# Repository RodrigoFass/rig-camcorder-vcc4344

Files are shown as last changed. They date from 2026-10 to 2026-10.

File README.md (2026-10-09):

# Rig camcorder para a Sanyo VCC-4344

Este rig transforma uma câmera de CCTV analógica (Sanyo VCC-4344) numa filmadora de mão com cara de VHS. Ele é **100 % impresso em 3D**: não usa nenhum parafuso, porca ou peça de metal, e a câmera fica só encaixada, sem usar os parafusos dela.

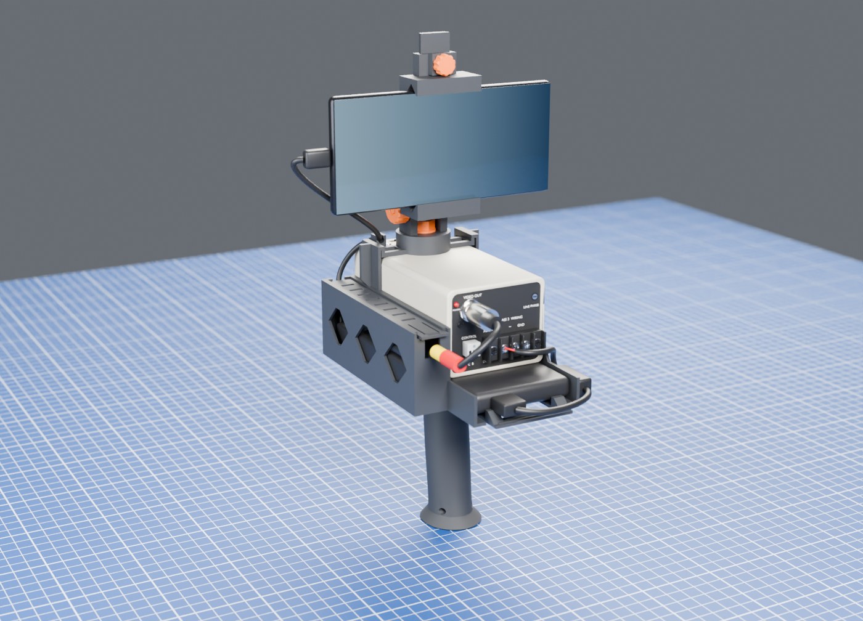
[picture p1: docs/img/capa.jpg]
Render do rig montado
<p align="center"><br><sub>Render do modelo. As travas extras aparecem nas imagens dos passos de montagem.</sub></p>

- **Câmera:** fica num berço que também guarda o power bank e a EasyCap.
- **Celular:** um Android serve de monitor e gravador. Ele fica numa articulação com giro, inclinação e rolagem.
  - **Opção fixa:** um clip de mola do MakerWorld, preso na base do giro, sem articulação. Veja [Suporte fixo do celular](docs/SUPORTE_CLIP.md).
- **Modelo paramétrico:** um único arquivo OpenSCAD (`scad/camcorder_rig_v6.scad`) gera todas as peças. As medidas da câmera, do power bank, da EasyCap, do celular e as folgas ficam no começo do arquivo.
- **Filamento:** ~180 g no rig completo (~80 g de PETG e ~100 g de PLA), mais ~16 g das peças de teste.

## Como cada parte prende

| Parte | Como prende |
|---|---|
| **Câmera** | Entra por trás no berço. O ferro (a chapa de suporte embaixo da câmera) corre sobre a sela, entre duas bochechas, até bater num batente. |
| **Ponte do topo** | Entra por trás, por baixo dos lábios das duas colunas. Os lábios descem para a frente, então a ponte funciona como cunha e aperta a câmera quando é empurrada. Uma moldura (trava da ponte) segura as colunas juntas. |
| **Power bank** | Molas no fundo do berço e uma trava traseira de encaixe. |
| **Cabo (empunhadura)** | Baioneta em rabo de andorinha: 2 garras sobem pelas janelas do berço e correm 13 mm para a frente. Uma chave trava. Veja [como o cabo prende](docs/img/como_o_cabo_prende.png). |
| **Giro, inclinação e rolagem** | Parafusos, porcas e botões impressos, com rosca de 8 mm e passo de 2 mm. A rosca é direita (aperta no sentido horário). |
| **Celular** | Garra com mordente que desliza e trava. A abertura (lado menor + espessura do celular) vai de ~68 a ~88 mm; o S21 dá 71,2 + 7,9 = 79,1 mm. Uma trava lateral com 2 cursores segura o celular nas pontas, para celulares de ~140 a ~172 mm de comprimento. Veja [como funciona](docs/img/como_funciona_trava_celular.png). |
| **EasyCap** | Caixa fechada do lado esquerdo do berço, com tampa deslizante e espaço para o adaptador OTG e as sobras de cabo. |

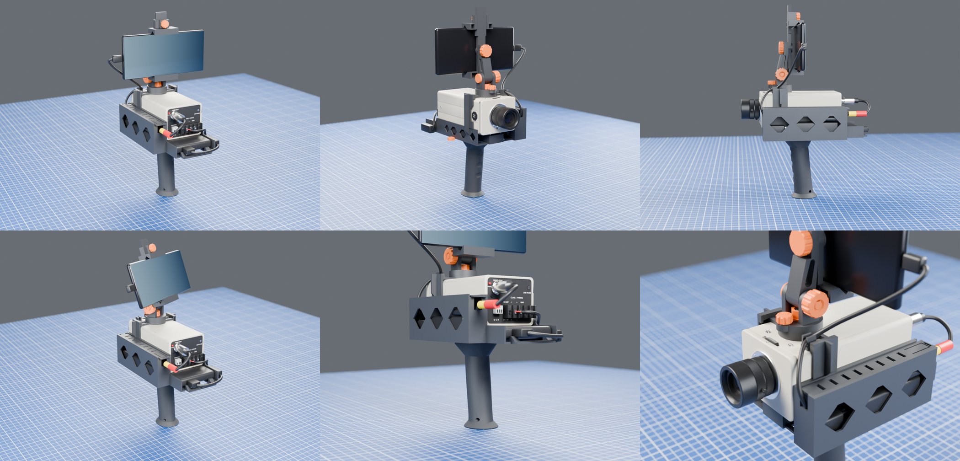
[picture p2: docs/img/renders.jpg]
Renders do rig


> **Lados:** "esquerdo" e "direito" são de quem segura o rig por trás, com a lente apontando para a frente. A caixa da EasyCap fica à esquerda e a chave do cabo entra pela direita.

## O que você precisa além das peças impressas

| Item | Observação |
|---|---|
| Câmera Sanyo VCC-4344 com lente CS | Medidas do modelo: corpo 67 × 126,5 × 54 mm. |
| Power bank | O modelo assume 124 × 67 × 13 mm. As molas absorvem ±1 mm na espessura. |
| Cabo USB 5 V → 12 V (step-up) | Alimenta a câmera pelo power bank. Prenda com 2 abraçadeiras ou barbante. |
| EasyCap (captura USB de vídeo AV) | O modelo assume 73 × 26 × 15,5 mm. **Nem toda EasyCap funciona no Android**: teste antes com um app de câmera USB. |
| Adaptador OTG (USB-A fêmea → USB-C) | Fica dentro da caixa. |
| Cabo BNC → RCA | Liga a saída de vídeo da câmera à EasyCap. |
| Celular Android | O modelo de referência é o Galaxy S21. No **iPhone** não funciona, porque o iOS não deixa apps usarem placas de captura USB. |
| EVA adesivo fino (opcional) | Dentro das mandíbulas da garra. |

## Peças

| Peça | Arquivo em `stl/` | Mesa (`mesas/`) | Qtd |
|---|---|---|---|
| Berço | `berco.stl` | 2 (PETG) | 1 |
| Tampa da caixa da EasyCap | `tampa.stl` | 2 (PETG) | 1 |
| Cabo | `cabo.stl` | 3 (PLA) | 1 |
| Ponte do topo (com o pino rosqueado do giro) | `topo.stl` | 3 (PLA)* | 1 |
| Garfo, braço, garra e mordente | `garfo.stl`, `braco.stl`, `garra.stl`, `mordente.stl` | 3 (PLA) | 1 de cada |
| Parafuso e porca-botão da inclinação, parafuso-botão da rolagem, parafusos de trava do giro e do mordente, porca e arruela em D do giro, chave do cabo | `parafusos.stl` | 4 (PLA) | 8 peças |
| Trava da ponte (moldura) | `trava_ponte.stl` | 5 (PETG) | 1 |
| Trava lateral do celular: calha, 2 cursores e 2 botões | `trava_celular.stl` | 6 (PLA) | 5 peças |
| Provas de encaixe | `testes_pla.stl`, `testes_petg.stl` | 1a / 1b | — |
| Porca-botão do suporte fixo (só na [opção com clip](docs/SUPORTE_CLIP.md)) | `porca_clip.stl` | 8 (PLA) | 1 |

\* A ponte fica apertada o tempo todo. Se ela ceder com o tempo, reimprima em PETG.

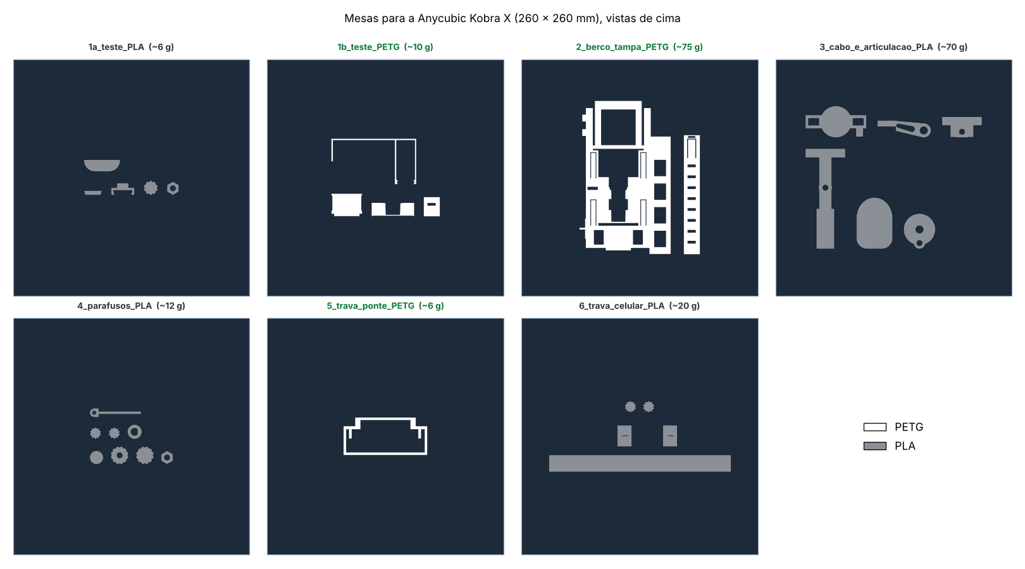
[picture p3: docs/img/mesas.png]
Mesas de impressão


As configurações do fatiador estão em [docs/COMO_IMPRIMIR.md](docs/COMO_IMPRIMIR.md). Nenhuma peça precisa de suporte. As maiores são o berço (101 × 169 × 78 mm), a calha da trava do celular (200 mm de comprimento) e o cabo (105 mm de altura, impresso em pé).

## Antes de imprimir: provas e ajustes

Imprima as mesas **1a** (PLA) e **1b** (PETG) e confira cada prova. Se algo ficar justo ou folgado, mude o parâmetro no começo do `.scad`:

| Prova | Deve ficar | Parâmetro |
|---|---|---|
| Parafuso + porca | Entra só com os dedos, sem ficar bambo | `TH_CL` (folga da rosca, 0,3 mm) |
| Garra do cabo + canal da baioneta | Corre e aperta no fim do curso | `DV_CL` |
| Espinha + mordente | Desliza sem folga | `SP_CL` |
| Sela | O ferro da sua câmera entra entre as bochechas sem forçar | `BRK_UW` (largura do ferro, 21,6 mm) |
| Fatia do berço | A câmera e o power bank cabem com folga pequena | `CL`, `PB`, `CAM_W` |
| Pedaço da tampa | Corre nos trilhos da fatia | `LID_X0`, `LID_X1`, `GR_Z1` (folgas da tampa) |

Os `.3mf` não se atualizam sozinhos. Depois de mudar um parâmetro, gere o STL de novo e importe no fatiador:

```bash
openscad -D 'PART="berco"' -o stl/berco.stl scad/camcorder_rig_v6.scad
```

Os nomes de `PART` são: `topo`, `berco`, `tampa`, `cabo`, `garfo`, `braco`, `garra`, `mordente`, `parafusos`, `trava_ponte`, `trava_celular`, `testes_pla` e `testes_petg`. Com `PART="montagem"`, o arquivo mostra tudo montado.

## Montagem

Não precisa de ferramenta. Cada passo indica para que lado ele é feito.

1. **Cabo:**
   - Vire o berço de cabeça para baixo.
   - Encaixe as 2 garras do topo do cabo nas 2 janelas do fundo do berço, com o cabo uns 13 mm para trás.
   - Empurre o cabo para a frente até parar firme.
   - Enfie a chave pelo rasgo de baixo do lado **direito** até a argola encostar.
   - Para tirar: puxe a chave pela argola e empurre o cabo para trás.
2. **Câmera:**
   - Apoie a câmera no berço, atrás das colunas, com o ferro na altura da sela.
   - Deslize para a frente até o ferro bater no batente. A bucha do ferro corre num canal da sela.
3. **Power bank:**
   - Empurre por trás, com as portas para trás, até a trava estalar.
   - Para tirar: aperte a ponta da trava (a cauda com ranhuras) para baixo e puxe.
4. **Ponte do topo e trava da ponte:**
   - Apoie a ponte em cima da câmera, atrás das colunas, com o gancho para a frente.
   - Empurre a ponte para a frente, por baixo dos lábios, até ficar bem firme.
   - Encaixe a trava da ponte por cima, em volta das duas colunas e da base do giro. Isso tem que ser feito **antes** de colocar o garfo.

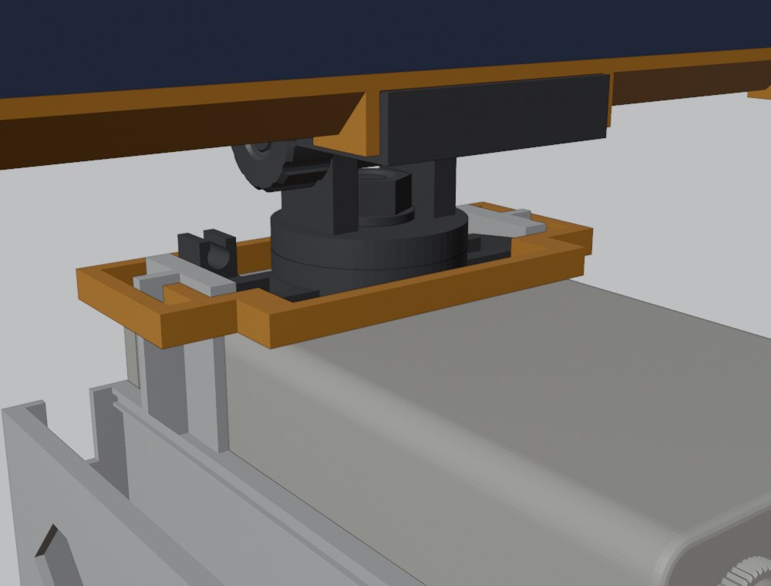
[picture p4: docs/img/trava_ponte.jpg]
Trava da ponte
   
5. **Giro:**
   - Coloque o garfo no pino, a arruela com furo em D e a porca sextavada.
   - Aperte até o garfo girar firme.
   - Rosqueie o parafuso da trava do giro na orelha da frente do garfo.
6. **Inclinação:**
   - Ponha o braço entre as orelhas do garfo.
   - Passe o parafuso pela orelha **direita**, com a face plana para cima, encaixando no furo em D.
   - Rosqueie a porca-botão do lado esquerdo.
7. **Rolagem:** encoste a garra atrás do braço e passe o parafuso-botão pela frente do braço, rosqueando na garra.
8. **Trava do celular e celular:**
   - Enfie um cursor em cada ponta da calha, com os botões para baixo e as paredes viradas para o meio.
   - Rosqueie um botão em cada cursor.
   - Encaixe a calha no V da garra de baixo, com os dedos abraçando as pontas da garra.
   - Ponha o celular com o USB-C para a esquerda.
   - Encoste os cursores nas pontas do celular e aperte os botões.
   - Enfie o mordente pelo topo da espinha, desça até encostar no celular e aperte o botão do mordente com firmeza.

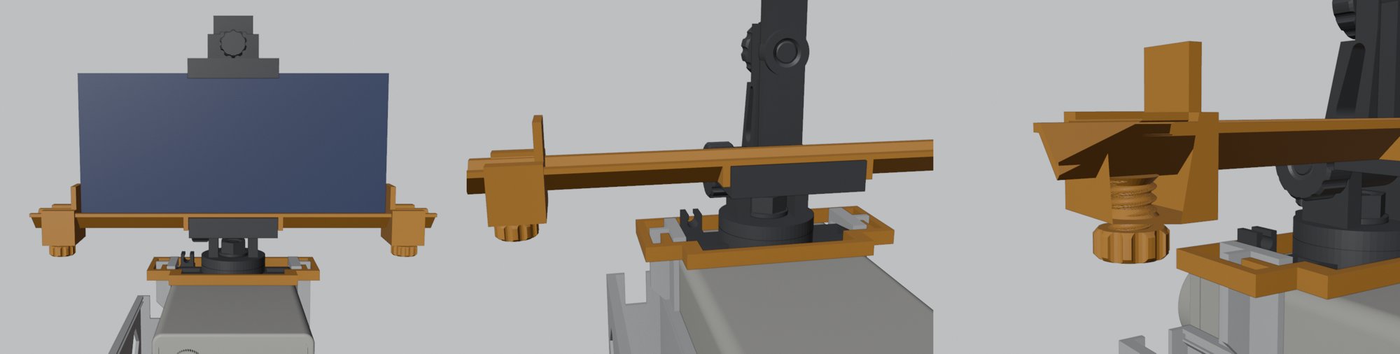
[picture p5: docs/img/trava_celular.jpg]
Trava lateral do celular
   
9. **EasyCap:**
   - Puxe a tampa da caixa pela ponta de trás, no rasgo para a unha.
   - Deite a EasyCap no fundo da caixa, com o USB para a frente, e encaixe o adaptador OTG.
   - Passe o cabo OTG pelo rasgo da frente e o RCA pelo rasgo de trás. As sobras de cabo ficam por cima.
   - Deslize a tampa por trás até clicar.

## Ligações

1. **Alimentação:**
   - Ligue o power bank ao cabo USB 5 V → 12 V e os fios aos bornes **DC 12V + e −** da câmera.
   - Prenda o step-up com abraçadeiras nas presilhas do lado direito do berço.
   - Confira a polaridade com multímetro antes de ligar. Não ligue nada nos bornes da entrada AC 24 V.
2. **Vídeo:** BNC "VIDEO OUT" → cabo BNC/RCA → RCA amarelo da EasyCap.
3. **Celular:**
   - Ligue o adaptador OTG ao celular passando pelo rasgo da frente e pelo gancho da ponte. Deixe uma folga perto da articulação.
   - No celular, use um app de câmera USB.

## Movimentos do celular

| Movimento | Faixa |
|---|---|
| Giro | 360° |
| Inclinação | −35° a +95° |
| Rolagem | ±30° |
| Inclinar para trás e rolar ao mesmo tempo | Com ±15° de rolagem, vai até −25°. Com ±30°, não incline para trás. |

## Verificações (`tools/`)

Os scripts conferem colisões entre todas as peças e a câmera (usando o modelo aproximado em `ref/`), varrem os movimentos do celular, calculam o centro de massa e estimam o filamento. Rode da raiz do repositório. Precisa de OpenSCAD 2021+ e Python 3 com os pacotes do `requirements.txt`.

```bash
pip install -r requirements.txt
bash tools/build6.sh asm_ topo berco tampa cabo chave porca trava_ponte garfo trava bincl braco garra brol mordente bmord trava_celular
python3 tools/check6.py          # colisões e movimentos
python3 tools/cog6.py            # centro de massa e estabilidade em pé
python3 tools/filamento.py stl/*.stl
```

**Resultado da v6:**
- **Colisões:** nenhuma entre as peças, nas faixas de movimento da tabela acima.
- **Equilíbrio:** o centro de massa fica a ~4 mm da mão.
- **Em pé:** o rig só tomba com mais de ~6° de inclinação.

## Glossário

- **Ferro:** a chapa de metal embaixo da câmera, onde normalmente vai a rosca de tripé.
- **Sela e bochechas:** o apoio do ferro no berço e as duas paredes que o guiam dos lados.
- **Lábios:** as abas no alto das colunas que seguram a ponte por cima.
- **Mordente:** a mandíbula de cima da garra do celular, que desliza na espinha.
- **OTG:** adaptador que deixa o celular usar um aparelho USB.
- **Step-up:** conversor que sobe os 5 V do power bank para os 12 V da câmera.
- **BNC:** o conector de vídeo da câmera.

## Histórico

- **v1–v4:** protótipos. Usavam os parafusos da câmera, uma luva e um pino impresso rosqueado no ferro, que quebrava.
- **v5:** berço sem os parafusos da câmera, caixa da EasyCap, garra ajustável e ~150 g de filamento. Ainda usava ferragens de metal.
- **v6 (atual):** 100 % impresso, com ponte em cunha, cabo em baioneta e roscas impressas. Depois do primeiro teste montado vieram a trava da ponte, a trava lateral ajustável do celular e parafusos de trava mais longos.

## Licença

© 2026 Rodrigo ([RodrigoFass](https://github.com/RodrigoFass)).

- **Peças, modelos e documentação** (`scad/`, `stl/`, `mesas/`, `docs/`, `ref/`): [CC BY-SA 4.0](LICENSE-HARDWARE.txt). Você pode usar, modificar e vender, desde que dê o crédito e compartilhe as modificações com a mesma licença.
- **Scripts** (`tools/`): [MIT](tools/LICENSE).

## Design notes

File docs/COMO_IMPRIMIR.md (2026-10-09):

# Como imprimir

As mesas da pasta `mesas/` foram montadas para a **Anycubic Kobra X** (mesa de 260 × 260 mm) e o **Anycubic Slicer Next**, mas abrem em qualquer fatiador que leia `.3mf`. As peças já vêm na posição certa. O material está no nome do arquivo, e no fatiador cada peça aparece como "PETG - …" ou "PLA - …". Em outra impressora, use os STLs da pasta `stl/`: eles já estão na posição de impressão.

| Ordem | Arquivo | Material | Filamento* |
|---|---|---|---|
| 1 | `1a_teste_PLA.3mf` | PLA | ~6 g |
| 1 | `1b_teste_PETG.3mf` | PETG | ~10 g |
| 2 | `2_berco_tampa_PETG.3mf` | PETG | ~75 g |
| 3 | `3_cabo_e_articulacao_PLA.3mf` | PLA | ~70 g |
| 4 | `4_parafusos_PLA.3mf` | PLA | ~12 g |
| 5 | `5_trava_ponte_PETG.3mf` | PETG (ou PLA) | ~6 g |
| 6 | `6_trava_celular_PLA.3mf` | PLA | ~20 g |
| 7 | clip do celular (opção fixa, [gere você mesmo](SUPORTE_CLIP.md)) | PETG | ~30 g |
| 8 | `8_porca_clip_PLA.3mf` (opção fixa) | PLA | ~3 g |

Na opção fixa com o clip, não precisa de garfo, braço, garra e mordente (mesa 3), da mesa 6 nem dos parafusos da articulação (mesa 4). A chave do cabo, que também sai na mesa 4, continua necessária.

\* Estimativa. O fatiador mostra o peso exato.

**Por que PETG no berço:** ele tem molas e travas que flexionam e fica encostado na câmera, que esquenta. O PLA amolece por volta de 55 °C e pode ceder.

## Configuração

### Mesas 1a, 1b, 2, 3 e 5
- **Processo:** 0.20mm Standard (camada de 0,2 mm).
- **Resistência:**
  - 3 paredes;
  - 4 camadas sólidas em cima e embaixo;
  - preenchimento de 15 % em **Giroide**. Evite Grade, que faz o bico raspar nas linhas já impressas.
- **Suporte:** desligado.
- **Borda (brim):** sem borda. A exceção é o cabo, na mesa 3: ligue brim de 5 mm só nele, porque ele imprime em pé. No Anycubic Slicer, clique com o botão direito no cabo e use a aba **Objetos**.
- **Velocidade:** com PETG, deixe a parede externa do berço em ~100 mm/s. As colunas são altas e finas.

A mesa 1a usa a mesma configuração da mesa 3 de propósito: assim a prova da rosca reproduz as roscas do garfo, da garra, do mordente e da ponte, que saem na mesa 3.

### Mesas 4 e 6 (parafusos, porcas, cursores)
- Camada de **0,12 mm**
- **5 paredes**
- **40 %** de preenchimento
- Parede externa a ~60 mm/s

### PETG em mesa de PEI liso
Passe cola bastão antes de imprimir. Sem ela, o PETG gruda demais e pode arrancar a película da mesa.

## Provas de encaixe

Imprima as mesas 1a e 1b antes das peças grandes. A tabela com o que conferir e qual parâmetro ajustar está no [README](../README.md#antes-de-imprimir-provas-e-ajustes).

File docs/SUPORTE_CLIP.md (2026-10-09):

# Suporte fixo do celular (clip do MakerWorld)

Esta opção troca a articulação (giro, inclinação e rolagem) por um suporte fixo. O celular fica num clip de mola preso na base do giro da ponte, com a tela para o operador e inclinado 15° para trás, com a tela apontando um pouco para cima.

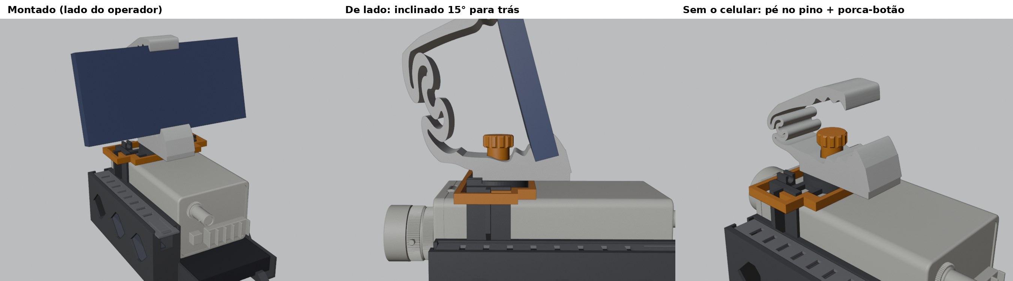
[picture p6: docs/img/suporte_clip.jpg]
Suporte fixo com o clip


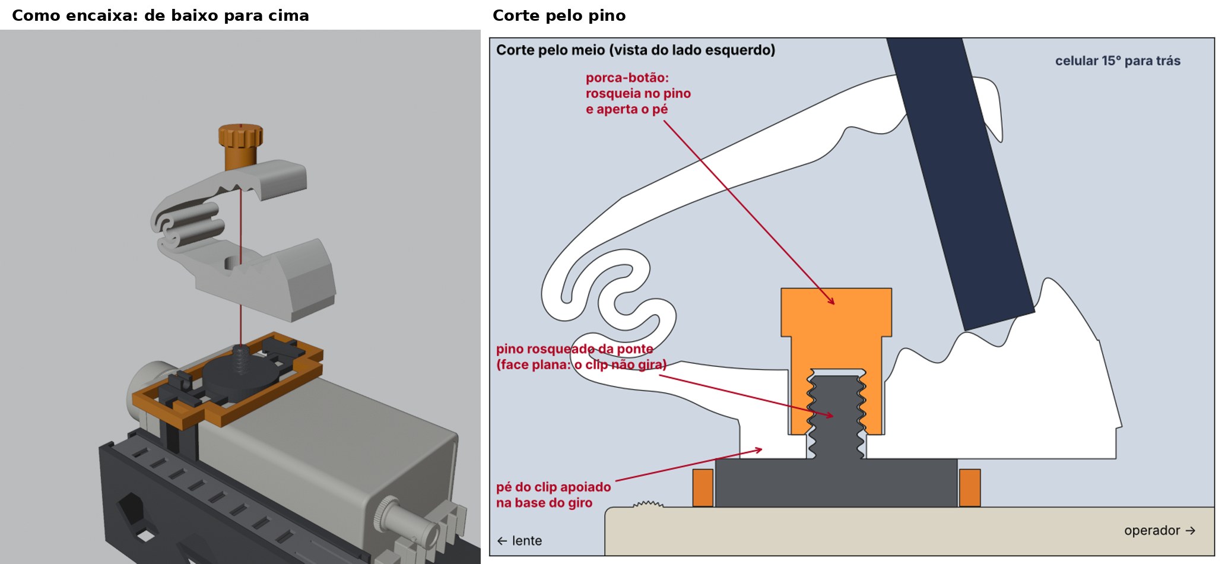
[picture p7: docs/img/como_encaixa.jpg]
Como o clip encaixa na ponte


O clip é o [Ultimate Desk & Cockpit Phone Holder Clip v3](https://makerworld.com/models/1158094), de **RealNationPrint**, impresso a 110 %, como no perfil do autor.
- **A garra de cima, com a mola em espiral,** segura o celular deitado pela altura. O fundo do celular fica nos dentes, atrás do lábio da frente, e a ponta da garra prende o topo.
- **A garra de baixo,** que prendia o clip no painel do carro, foi tirada.
- **No lugar dela entra um pé,** com furo em D que encaixa no pino do giro. A face plana do pino impede o clip de girar.
- **Uma porca-botão** rosqueia no pino por cima e aperta o pé contra a base.
- **Inclinação:** o corpo do clip é inclinado 15° em cima do pé, que continua reto na base. Para mudar, altere `CL_INC` no `.scad`.

## O arquivo do clip não vem neste projeto

A licença do autor (Standard Digital File License) não permite redistribuir o modelo nem versões modificadas dele. Por isso o perfil do clip não está no repositório. Para gerar o clip adaptado:

1. Baixe o `.3mf` do clip na página do MakerWorld.
2. Na raiz do repositório, rode:
   ```
   python3 tools/clip_perfil.py ClipV3.3mf
   ```
   Isso grava `scad/clip_v3_perfil.scad`, que fica fora do git.
3. Gere as peças:
   ```
   openscad -D 'PART="clip"' -o clip.stl scad/camcorder_rig_v6.scad
   openscad -D 'PART="porca_clip"' -o porca_clip.stl scad/camcorder_rig_v6.scad
   ```

O arquivo gerado é só para uso pessoal.

## Impressão

| Peça | Material | Configuração | Filamento* |
|---|---|---|---|
| Clip (`PART="clip"`) | **PETG** | Deitado, com o perfil na mesa. Camada de 0,2 mm, 3 paredes, 25 % de preenchimento, sem suporte. | ~30 g |
| Porca-botão (`PART="porca_clip"`) | PLA | Botão na mesa. Mesma configuração das porcas (mesa 4): camada de 0,12 mm, 5 paredes, 40 %. | ~3 g |

\* Estimativa. O fatiador mostra o peso exato.

- **Por que PETG no clip:** a mola em espiral flexiona muito para o celular entrar. Em PLA ela pode trincar.
- **Furos sem suporte:** o furo em D sai com o teto reto e o rebaixo da porca sai em gota.

## Montagem

1. **Peças da articulação:** tire o garfo e tudo o que fica nele: braço, garra, mordente, os parafusos e a porca sextavada do giro com a arruela.
   - A ponte, a trava da ponte (moldura) e o resto do rig ficam como estão.
2. **Clip:**
   - Encaixe o pé do clip no pino do giro, com a mola em espiral para a frente (lado da lente) e os dentes para trás.
   - O furo em D só entra numa posição.
3. **Porca-botão:**
   - Coloque a porca-botão no pino por cima do corpo do clip.
   - Aperte com os dedos, no sentido horário, até o pé ficar firme.
4. **Celular:**
   - Levante a garra de cima.
   - Apoie o celular nos dentes, com a tela para trás e encostado no lábio.
   - Solte a garra sobre o topo do celular.
   - Deixe o USB-C para a esquerda, do lado da EasyCap.

**Opcional:** EVA fino adesivo nos dentes, para o celular não escorregar para os lados.

## Conferido no computador

- **Interferências:** o clip não bate na câmera nem na trava da ponte. Ficam 7 mm até o topo da câmera e 1,5 mm até a moldura.
- **Folgas:**
  - furo em D no pino: 0,2 mm;
  - porca-botão no rebaixo: 0,4 mm;
  - botão até o corpo do clip: 2,3 mm.
- **Celular:**
  - Fica inclinado 15° para trás, de Z 52 a 126 mm, uns 6 mm mais baixo que na articulação.
  - Sobram 8 mm entre o celular e a porca-botão.
- **Equilíbrio:** o centro de massa fica ~1,5 mm atrás da mão. Antes ficava ~4 mm.
- **Em pé na mesa:** o rig só tomba se inclinar mais de ~6°.

Para refazer as contas: `tools/check_clip.py` e `tools/cog_clip.py`.

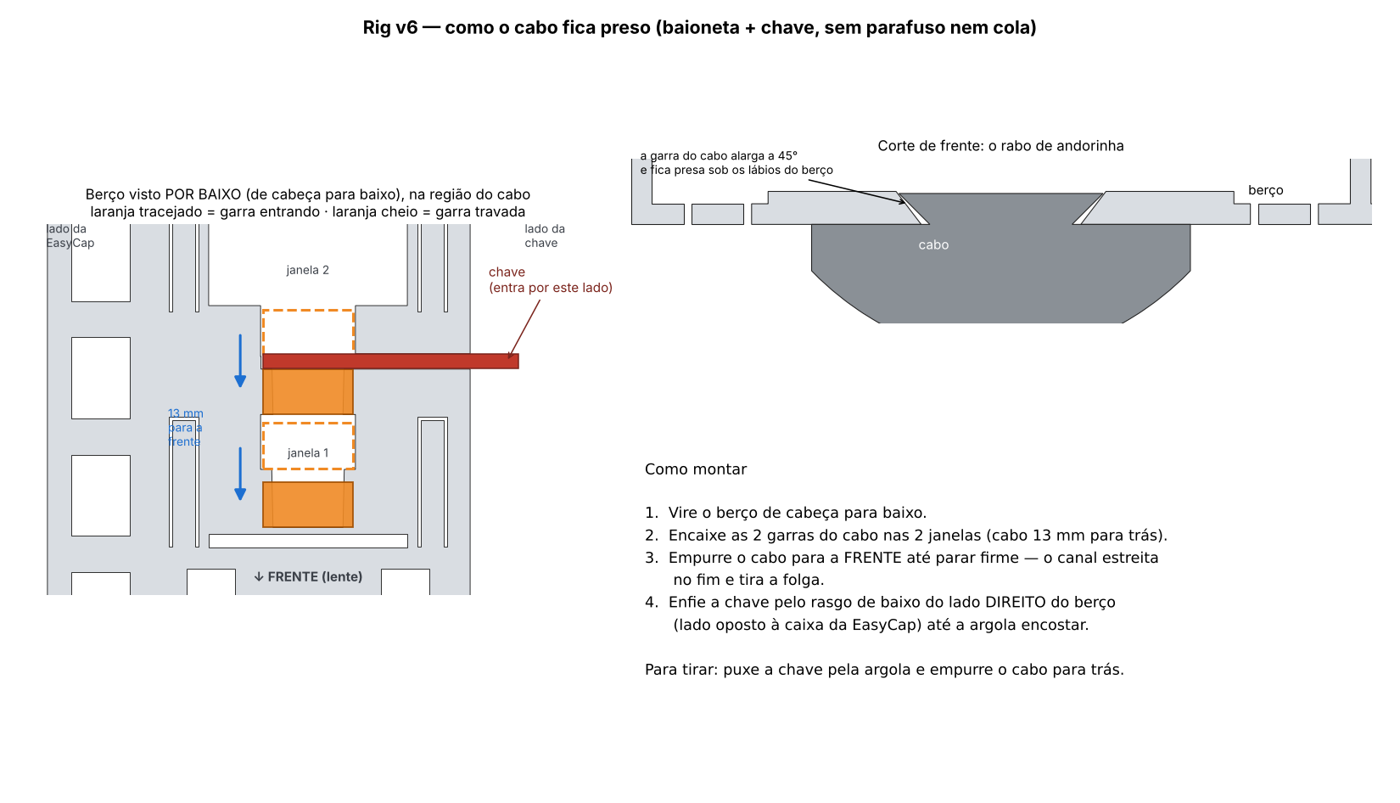
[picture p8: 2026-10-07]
docs/img/como_o_cabo_prende.png

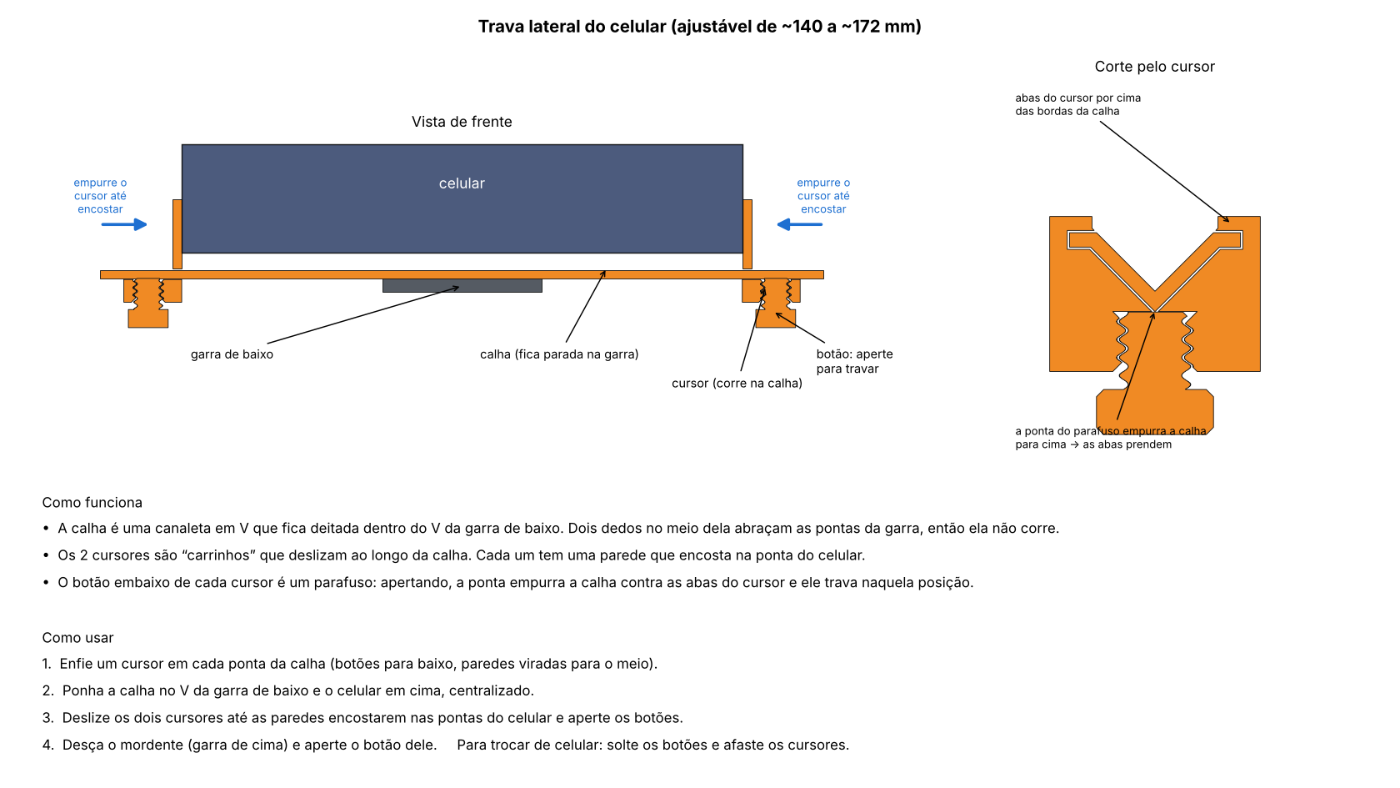
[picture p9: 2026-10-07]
docs/img/como_funciona_trava_celular.png

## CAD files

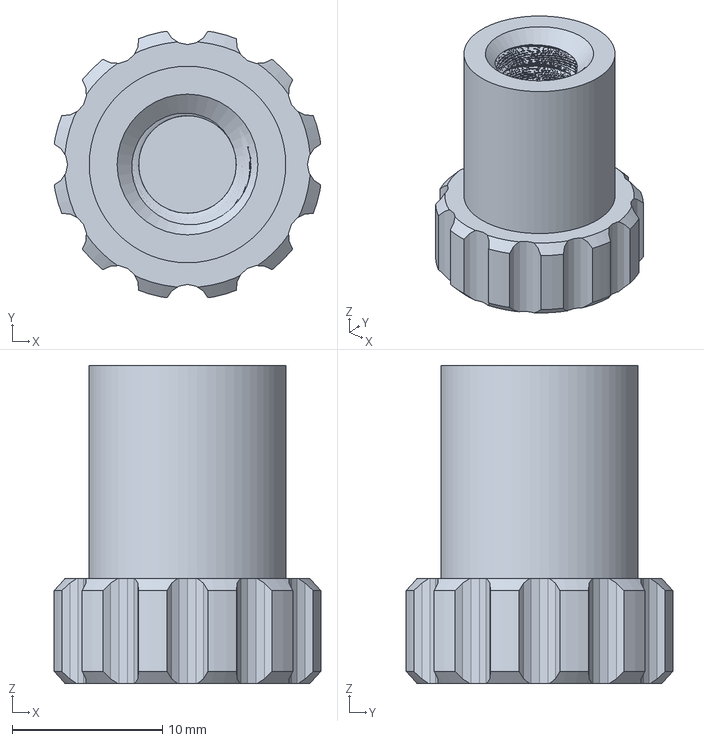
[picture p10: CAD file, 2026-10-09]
mesas/8_porca_clip_PLA.3mf
17.8 x 17.8 x 21.2 mm

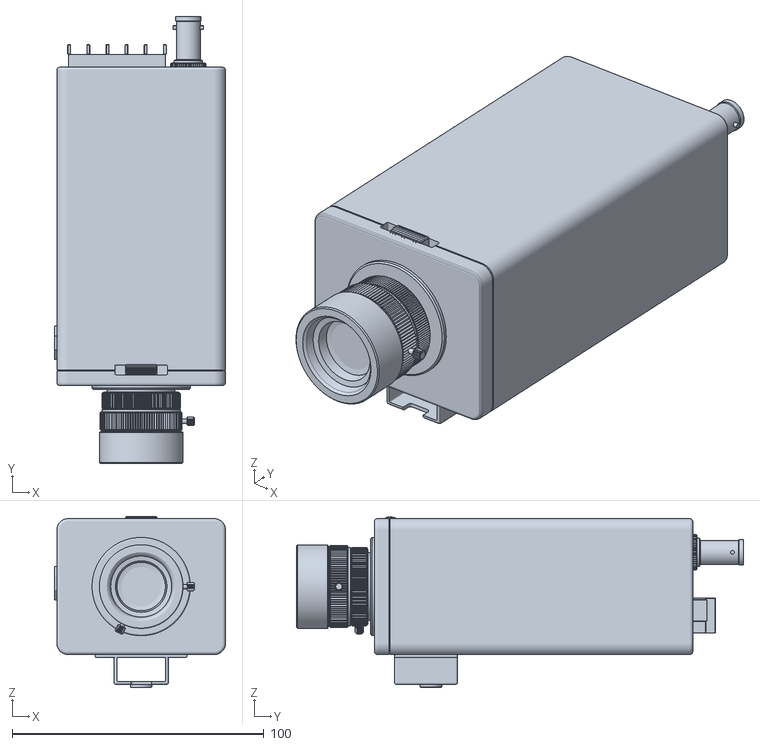
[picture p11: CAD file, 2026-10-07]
ref/sanyo_vcc4344_mm.stl
67.9 x 177.5 x 68.1

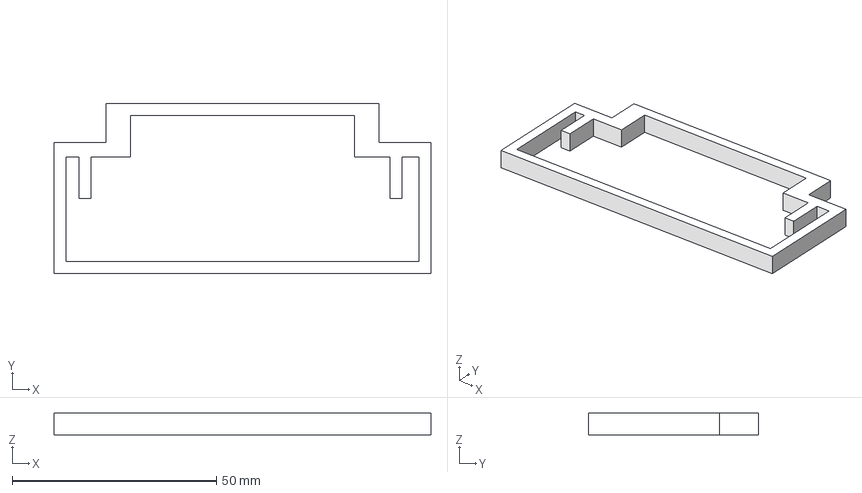
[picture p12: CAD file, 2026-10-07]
mesas/5_trava_ponte_PETG.3mf
92.4 x 41.7 x 5.35 mm

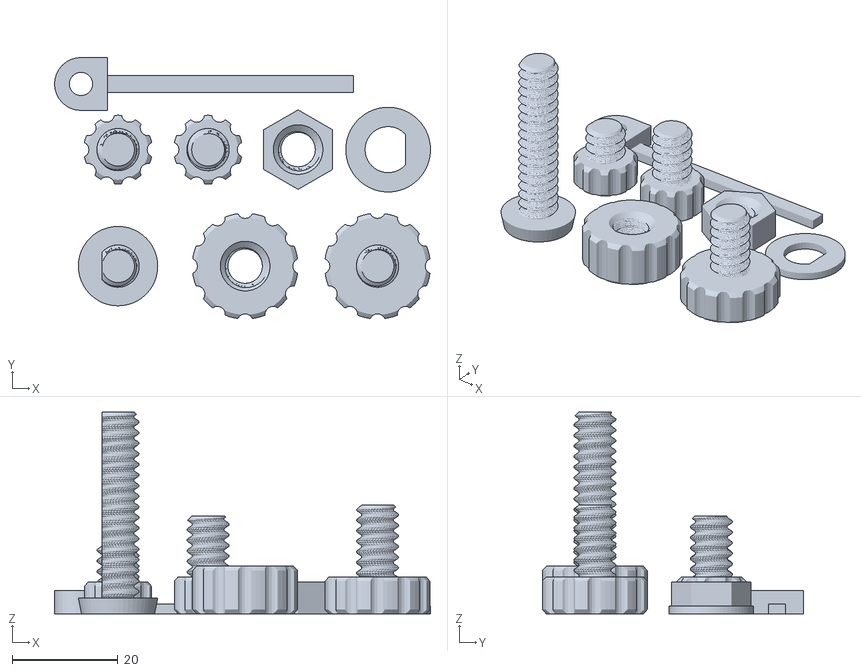
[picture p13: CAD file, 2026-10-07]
stl/parafusos.stl
71.0 x 49.3 x 38.1

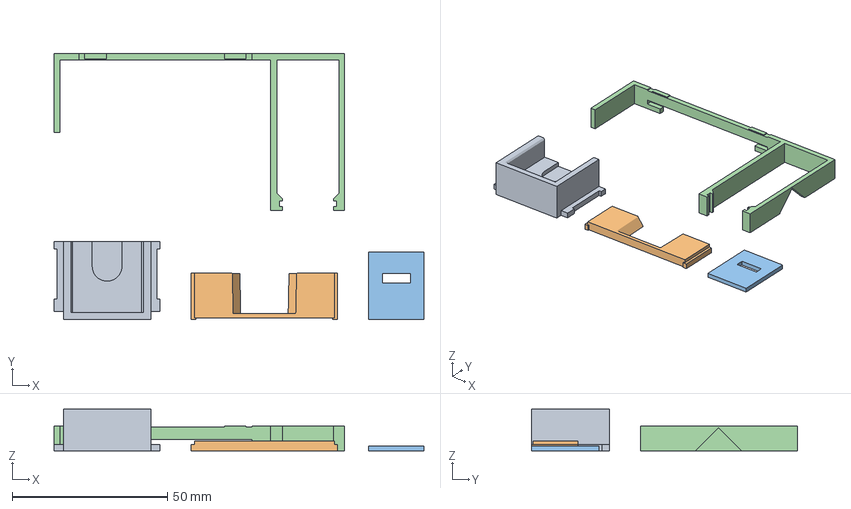
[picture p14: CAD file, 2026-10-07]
mesas/1b_teste_PETG.3mf
119.2 x 85.6 x 13.4 mm
PETG - teste_sela
PETG - teste_baioneta_berco
PETG - teste_tampa
PETG - teste_fatia_berco_e_caixa

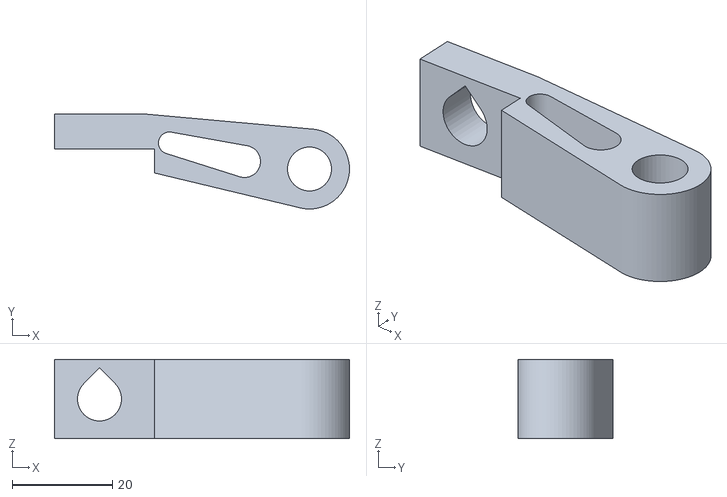
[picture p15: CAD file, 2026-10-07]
stl/braco.stl
59.0 x 19.0 x 15.8

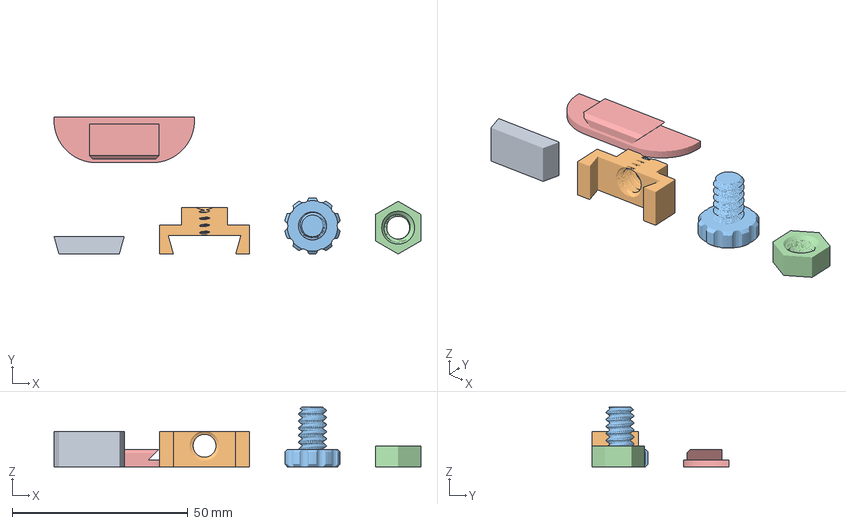
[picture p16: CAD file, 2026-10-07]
mesas/1a_teste_PLA.3mf
104.5 x 39.0 x 17.0 mm
PLA - teste_espinha_garra
PLA - teste_mordente
PLA - teste_rosca_parafuso
PLA - teste_rosca_porca
PLA - teste_baioneta_cabo

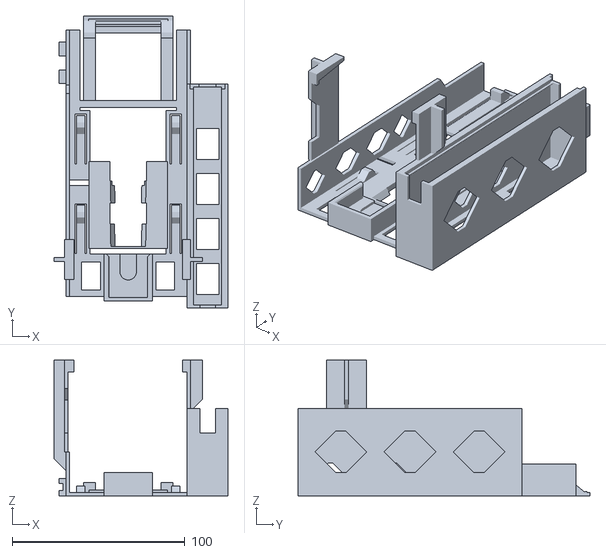
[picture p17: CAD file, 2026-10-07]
stl/berco.stl
100.6 x 168.9 x 78.4

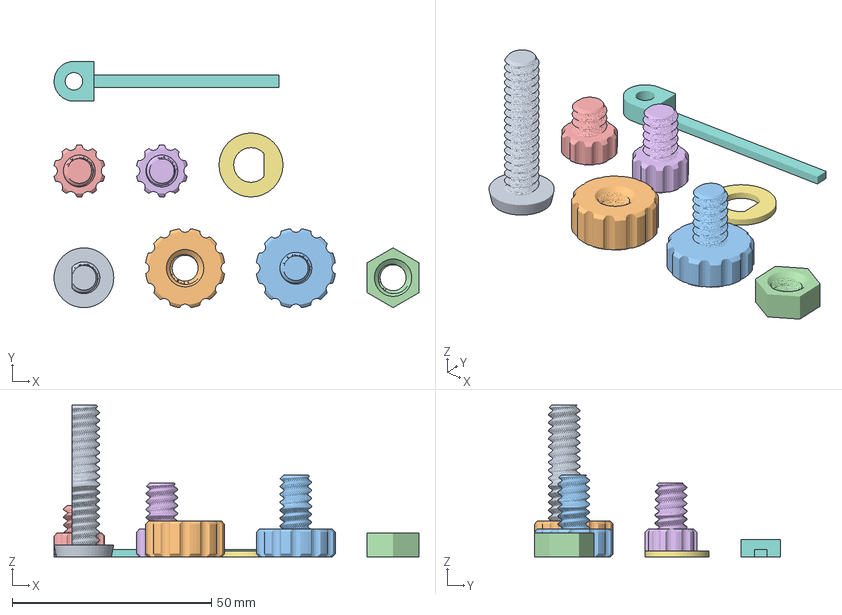
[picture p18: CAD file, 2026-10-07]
mesas/4_parafusos_PLA.3mf
91.6 x 61.8 x 38.1 mm
PLA - parafuso_inclinacao
PLA - porca_botao_inclinacao
PLA - parafuso_rolagem
PLA - porca_giro
PLA - parafuso_trava_giro
PLA - parafuso_mordente
PLA - arruela_giro
PLA - chave_do_cabo

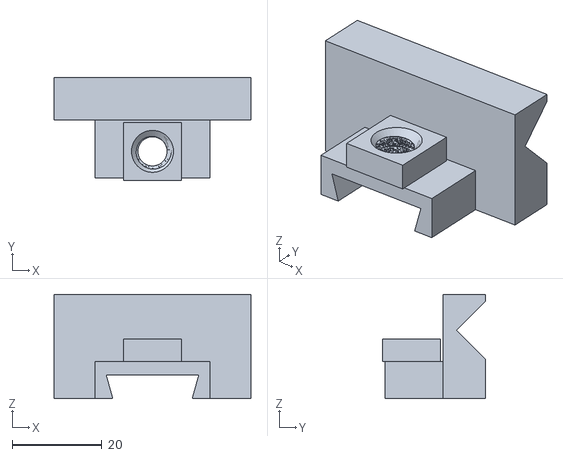
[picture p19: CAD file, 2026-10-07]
stl/mordente.stl
44.0 x 23.0 x 23.2

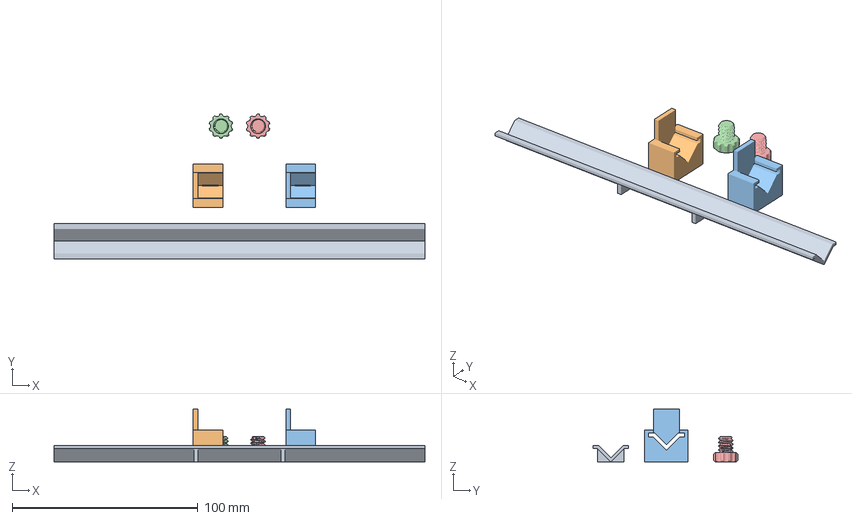
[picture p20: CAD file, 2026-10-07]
mesas/6_trava_celular_PLA.3mf
200.0 x 78.0 x 28.5 mm
PLA - calha
PLA - cursor_1
PLA - cursor_2
PLA - botao_cursor_1
PLA - botao_cursor_2

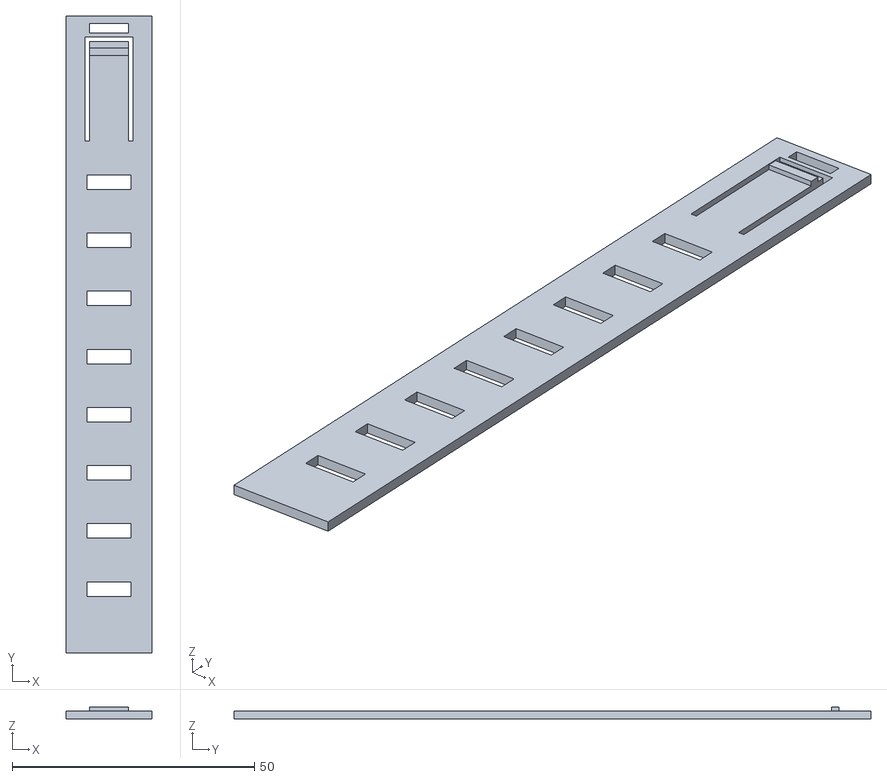
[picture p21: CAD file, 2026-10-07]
stl/tampa.stl
17.8 x 131.5 x 2.40

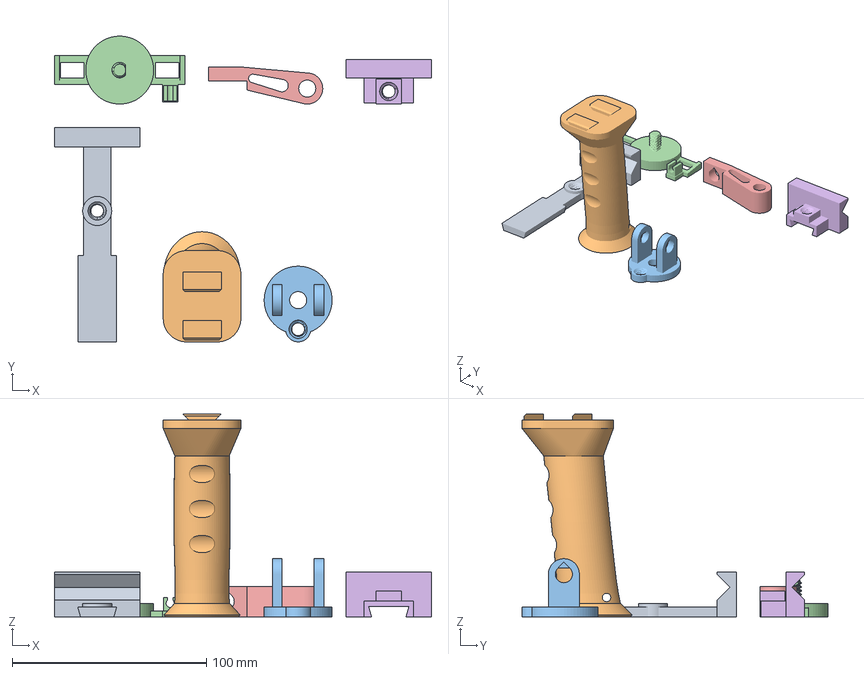
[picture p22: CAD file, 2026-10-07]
mesas/3_cabo_e_articulacao_PLA.3mf
194.2 x 157.5 x 104.5 mm
PLA - garra
PLA - cabo
PLA - garfo
PLA - ponte_topo
PLA - braco
PLA - mordente

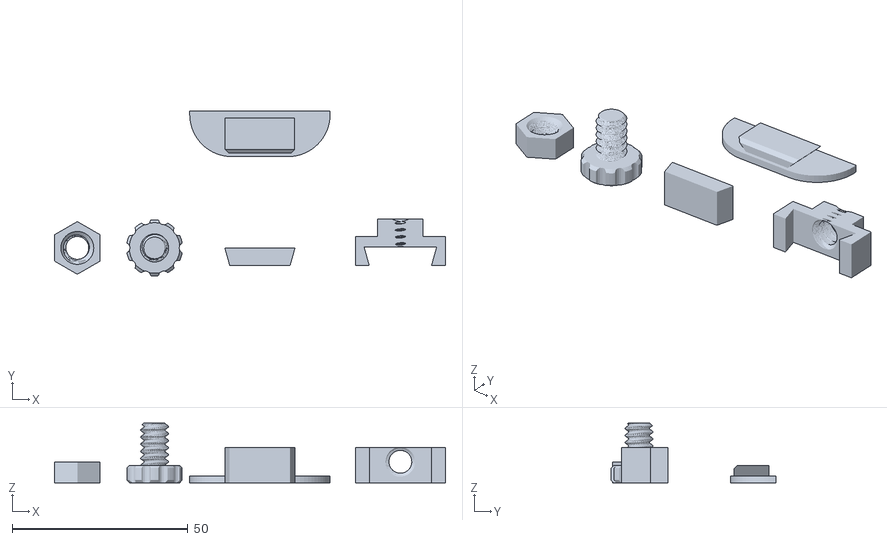
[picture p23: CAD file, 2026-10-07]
stl/testes_pla.stl
111.3 x 47.0 x 17.0

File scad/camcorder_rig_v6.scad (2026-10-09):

// SPDX-License-Identifier: CC-BY-SA-4.0   © 2026 Rodrigo (github.com/RodrigoFass)
// =====================================================================
//  Rig camcorder v6 — Sanyo VCC-4344  (100 % impresso: nenhum parafuso, porca ou peça de metal)
//  A câmera (metal) é a estrutura e fica só encaixada; nenhum parafuso da câmera é usado.
//  Tudo o que rosqueia é impresso: rosca de 8 mm, passo 2 (perfil liso de círculo excêntrico torcido).
//    • berço   : abraça a base da câmera. A câmera entra por trás: o ferro corre sobre a sela, entre
//                duas bochechas, até o batente da frente. Duas colunas com lábios em cunha seguram a
//                ponte do topo. Power bank preso por molas e trava traseira; EasyCap numa caixa fechada
//                no lado +X, com tampa deslizante.
//    • topo    : ponte que entra por trás sob os lábios das colunas e aperta a câmera ao ser empurrada
//                para a frente (cunha). O pino rosqueado do giro sai impresso junto.
//    • cabo    : empunhadura presa por baioneta em rabo de andorinha (2 garras entram por janelas e
//                correm 13 mm para a frente), travada por uma chave que entra pelo lado −X.
//    • garfo, braço, garra, mordente: giro, inclinação e rolagem do celular, com parafusos, porcas e
//                botões impressos. A garra abre de 70 a 90 mm (altura + espessura do celular).
//  Coordenadas (mm): X = largura (+X = esquerda do operador), Y = comprimento (lente em −Y),
//  Z = altura; origem no centro do corpo da câmera.
//    • extras : trava da ponte (moldura em volta das colunas) e trava lateral do celular ajustável
//    • opção fixa: clip de mola do MakerWorld na base do giro, no lugar da articulação (veja o fim do arquivo)
//  Uso: openscad -D 'PART="berco"' -o berco.stl camcorder_rig_v6.scad
//       PART = montagem (com o clip) | montagem_articulada | topo | berco | tampa | cabo | garfo | braco | garra |
//              mordente | parafusos | trava_ponte | trava_celular | clip | porca_clip | testes_petg | testes_pla
// =====================================================================

PART = "montagem";
$fn = 64;

// ---------------------------------------------------------- câmera (manual + fotos)
CAM_W = 67;  CAM_L = 126.5;  CAM_H = 54;  CAM_R = 4.5;
YF = -CAM_L/2;  YB = CAM_L/2;  ZT = CAM_H/2;  ZB = -CAM_H/2;
BRK_Y0 = YF + 8;  BRK_Y1 = YF + 33;  BRK_UW = 21.6;  BRK_H = 12;
BRK_ZB = ZB - BRK_H + 0.02;                  // fundo da chapa do ferro (−38,98)
BUCHA_Y = YF + 22.5;  BUCHA_R = 4.3;  BUCHA_H = 1.2;

// ---------------------------------------------------------- componentes (confira com paquímetro)
PB = [124, 67, 13];         // power bank: comprimento (Y), largura (X), espessura (Z)
EC_A = 73;  EC_B = 26;  EC_C = 15.5;  EC = [EC_A, EC_B, EC_C];        // EasyCap sem o plugue (scan: ~72 x 25,5 x 15): comprimento (Y), altura (Z), espessura (X)
PH = [151.7, 71.2, 7.9];    // celular na montagem (Galaxy S21): comprimento, altura, espessura

// ---------------------------------------------------------- roscas impressas
TH_D = 8;  TH_P = 2;        // diâmetro externo e passo
TH_E = 0.5;                 // excentricidade (a rosca tem 2·TH_E = 1 mm de profundidade)
TH_CL = 0.3;                // folga radial da fêmea (ajuste com a peça de teste)

// ---------------------------------------------------------- berço
CL = 0.4;  W = 2.0;                          // folga lateral e parede
XI = max(PB[1], CAM_W)/2 + CL;               // face interna das paredes (33,9)
XO = XI + W;                                 // face externa (35,9)
Z_PB0 = ZB - PB[2];                          // fundo do power bank (−40); o topo encosta na câmera
SPR_GAP = 2.4;                               // vão das molas embaixo do power bank
LIP_Z1 = Z_PB0 - SPR_GAP;                    // topo das abas (−42,4)
LIP_Z0 = LIP_Z1 - 2.0;                       // fundo do berço (−44,4)
XL = XI - 6;                                 // borda interna das abas (27,9)
WALL_Z1 = ZB + 8;                            // paredes sobem 8 mm nas laterais da câmera
WALL_Z1B = ZB + 1;                           // atrás da câmera só seguram o power bank
PB_Y0 = BRK_Y1 + 0.4;  PB_Y1 = PB_Y0 + PB[0];
CH_Y0 = BRK_Y0;  CH_Y1 = PB_Y1 + 5;
// sela sob o ferro: bochechas dos lados, batente na frente e canal da bucha (a câmera entra por trás)
SAD_Z1 = BRK_ZB - 0.02;  SAD_Y1 = PB_Y0 - 0.6;
SC_X0 = BRK_UW/2 + 0.3;  SC_X1 = SC_X0 + 3;  SC_Z1 = ZB - 4;      // bochechas (faces internas a 0,3 mm do ferro)
FEN_Y1 = BRK_Y0 - 0.35;  FEN_Y0 = FEN_Y1 - 2.25;                 // batente na frente do ferro
// molas: 4 linguetas que empurram o power bank contra a câmera (absorvem ±1 mm de espessura)
SPR_X = 27.5;  SPR_W = 5;  SPR_L = 28;  SPR_UP = 1.3;
SPR_YC = [PB_Y0 + 22, PB_Y0 + 74];           // crista das molas (sempre embaixo da câmera)
function spr_y0(yc) = yc - 22.5;
// trava traseira: lingueta em U no fundo; aperte a ponta para baixo para soltar
LAT_Y0 = PB_Y1 - 36;  LAT_X0 = 19;  LAT_X1 = 26;  LAT_T = 1.8;
HOOK_Y0 = PB_Y1 + 0.3;  HOOK_L = 3;  HOOK_Z = Z_PB0 + 3.2;  TAIL_Y1 = PB_Y1 + 13;
// caixa da EasyCap (+X): EasyCap deitada no fundo, adaptador OTG na frente, sobras de cabo por cima; tampa deslizante
EB_T = 1.8;                                  // paredes da caixa
EB_X0 = XO;  EB_X1 = XO + 20;                // faces internas (a de dentro é a parede do berço, prolongada)
EB_Y0 = -60;  EB_Y1 = 66;                    // faces internas da frente e de trás
EB_Z0 = LIP_Z0 + 2;  EB_Z1 = 2;              // fundo e topo do espaço interno
RL_W = 1.8;  GR_D = 1.0;  LID_T = 1.6;       // trilhos da tampa, fundo da canaleta, espessura da tampa
GR_Z0 = EB_Z1 + 1.0;  GR_Z1 = GR_Z0 + LID_T + 0.3;   // canaleta da tampa
RL_Z1 = GR_Z1 + 1.2;                         // topo dos trilhos e da frente
LID_X0 = EB_X0 + RL_W - GR_D + 0.3;  LID_X1 = EB_X1 - RL_W + GR_D - 0.3;
LID_Z0 = GR_Z0 + 0.15;  LID_Y1 = EB_Y1 + EB_T + 4;
// EasyCap na montagem: deitada no fundo, encostada na parede de fora, USB para a frente
EC_X0 = EB_X1 - EC[2] - 0.5;  EC_Y0 = -18;  EC_Z0 = EB_Z0;
TST_Y = 50.5;                                // fatia de teste do berço (inteira: travessa + caixa)
// janelas das paredes (ventilação e menos material)
WIN_Z0 = LIP_Z1 + 3.5;  WIN_Z1 = ZB + 1.5;
WIN_PX = [[-51, -35], [-15, 2], [12, 29.6]];
WIN_NX = [[-51, -35], [-26, -6], [0, 20], [23, 37.5]];

// ---------------------------------------------------------- cabo (empunhadura) e baioneta
HY_C = -2;                                   // centro do topo do cabo; fica sob o centro de massa
HF_Y0 = HY_C - 25;  HF_Y1 = HY_C + 25;       // piso do berço sobre o cabo
CABO_H = 96;  CABO_RAKE = 6;
HF_T = 4.5;  HF_Z1 = LIP_Z0;  HF_Z0 = HF_Z1 - HF_T;
CF_X = 20;  CF_Y0 = HY_C - 25;  CF_Y1 = HY_C + 22;   // flange do cabo (encosta embaixo do berço)
// rabo de andorinha a 45°: o berço tem o canal (bloco embaixo do power bank), o cabo tem 2 garras
DV_H = 3.2;  DV_N = 7;                       // altura e meia-largura do pescoço
DV_CL = 0.1;                                 // folga das garras; o canal estreita até a frente (cunha)
DV_L = 10;  DV_RUN = 13;                     // comprimento das garras e curso da baioneta
DV_Y = [HY_C - 24, HY_C + 1];                // frente das garras, assentadas
BLK_X = 22.6;  BLK_Y0 = HY_C - 25.5;  BLK_Y1 = HY_C + 25;
// chave: barra 3,2 x 1,9 mm que entra pelo lado −X, por baixo do berço, atrás da garra de trás
KEY_W = 3.2;  KEY_H = 1.9;  KEY_Y = DV_Y[1] + DV_L + 0.05;  KEY_X0 = -XO - 0.6;  KEY_X1 = 10;
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

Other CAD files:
stl/porca_clip.stl
mesas/2_berco_tampa_PETG.3mf
stl/cabo.stl
stl/garra.stl
stl/garfo.stl
stl/testes_petg.stl
stl/topo.stl
stl/trava_celular.stl
stl/trava_ponte.stl

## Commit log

2026-10-07 Rig camcorder v6 para a Sanyo VCC-4344 (100% impresso)
    Modelo paramétrico em OpenSCAD, STLs, mesas .3mf para a Kobra X,
    guia de impressão e montagem e scripts de verificação.
    [1a_teste_PLA.3mf, 1b_teste_PETG.3mf, 2_berco_tampa_PETG.3mf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]
2026-10-09 Suporte fixo do celular com o clip do MakerWorld
    Opção sem articulação: o clip de mola (RealNationPrint, MakerWorld 1158094)
    fica preso na base do giro por um pé com furo em D e uma porca-botão impressa.
    O perfil do clip não é distribuído (licença do autor); tools/clip_perfil.py
    gera o arquivo a partir do .3mf baixado por cada um.
    [8_porca_clip_PLA.3mf, camcorder_rig_v6.scad, porca_clip.stl]
2026-10-09 Clip do celular inclinado 15° para trás
    O corpo do clip inclina sobre o pé, que continua reto na base do giro
    (parâmetro CL_INC). Inclui o desenho de como o clip encaixa no pino.
    [8_porca_clip_PLA.3mf, camcorder_rig_v6.scad]
2026-10-11 Pé do clip estendido sobre a barra da frente da trava da ponte
    A aba desce até 0,3 mm da moldura, então ela não sobe com o clip montado.
2026-10-12 Clip com o pé de fundo reto e mesa única com a porca-botão
    Tira a aba que descia até a moldura; o pé continua estendido por cima dela.
    Novo PART clip_e_porca: clip e porca-botão na mesma mesa, em PETG.
2026-10-12 Imagens e documentação do modelo com o clip fixo
    Capa, renders, trava da ponte e mesas refeitos com o clip do celular.
    README passa a descrever o clip; a articulação foi para docs/ARTICULACAO.md.
    Nova mesa 3_cabo_ponte_chave_PLA (sem as peças da articulação) e stl/chave.stl.
